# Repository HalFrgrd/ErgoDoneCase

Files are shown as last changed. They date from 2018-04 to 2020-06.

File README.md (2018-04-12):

# ErgoDoneCase
An acrylic case for the ErgoDone PCBs
---
I bought two [ErgoDone PCB's from KBDFans](https://kbdfans.myshopify.com/collections/pcb/products/ergodone-keyboard-pcb-1pcs-free-shipping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) and modified [Litster's ErgoDox acrylic case](https://github.com/bishboria/ErgoDox) to accommodate the changed PCBs. The PCBs are a little different to the standard ErgoDox design:

* Microcontroller is an Arduino Pro Micro instead of Teensy.
* Microcontroller is on left handside instead of right handside.
* IO expander changed from MCP23018 to MCP23017.
* IO expander is now on the right handside.
* Resistors have changed place and orientation.
* LEDs are located on the lefthandside on the top right.

Like Litster's, 3mm acrylic should be used for layers 1 and 5, and 4mm acrylic for the middle layers.
I only had 3mm acrylic so I added nuts between layers 2 and 3 to reaise the PCB. 20mm screws were perfect.

If you want the design without a handrest, replace the bottom half of my designs with the bottom edge of the handrestless designs from Litster. 

See this link about flashing: https://github.com/qmk/qmk_firmware/blob/master/keyboards/ergodox/readme.md

Look at the assembled 2 Layer case album: https://imgur.com/a/fJbaJ

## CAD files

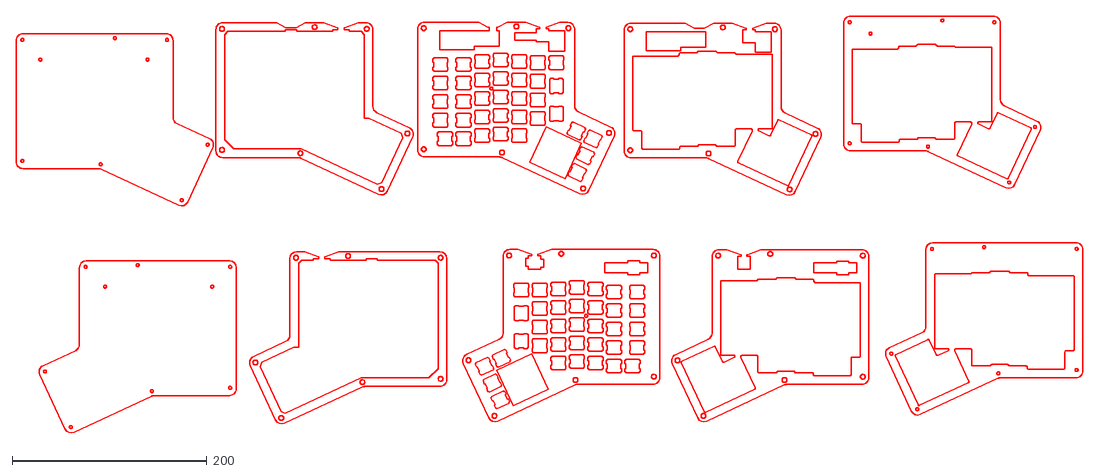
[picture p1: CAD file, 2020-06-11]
ergodonecaseoriginal_standard.dxf
1095.3 x 429.0

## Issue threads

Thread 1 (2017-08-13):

Assembly instructions

harshitgoel96, 2017-08-13:
How to place the pcb inside the case

HalFrgrd, 2017-08-14:
The PCB goes in beneath layer 3. It is held in place by the switches which sit on top of layer 3. Since there is a large number of switches and 2 solder points on each one, the PCB is held in place quite well.

harshitgoel96, 2017-08-15:
Would it be possible for you to make some changes to design to further reduce the design cost? Could you change the  switch plate cutout with Non top removal cutout. And a big rectangle instead of Costar stabilizer. As I want to use Cherry PCB stabilizer

HalFrgrd, 2017-08-16:
What do you mean by non top removal cutout? Do you mean just not having a switch plate?
For the stabilisers, yeah I think I will because with Cherry, they are more popular, and you can mount them into the switch plate from the top, so if you already soldered the switches, you can put in the stabs.

harshitgoel96, 2017-08-16:
The switch plate with perfect square for switches. The one without the space for two clips on both side.

HalFrgrd, 2017-08-16:
Have a look at this website:
http://builder.swillkb.com/
and get the JSON output from this website: http://www.keyboard-layout-editor.com/
Then select square holes and Cherry stabilisers. This will allow you to get the right sizes for the keyholes and the stabiliser holes. It would take a bit of time to modify the switch plate with these new shapes.
Feel free to ask me if you're unsure.

harshitgoel96, 2017-08-16:
i am aware of this. sadly i know nothing about how to modify the file. i lack designing skills

harshitgoel96, 2017-08-19:
hi. i checked the case and plate builder and pulled the ergodox design from kle, but the switch do not align. can you please confirm if they should align or not ?

HalFrgrd, 2017-08-21:
Hi, I have added another design that I think is what you want. The design is different from the one KLE but my design fits the PCB's. KLE might need to update their design as I think it is for an older version of the ErgoDox PCB.

harshitgoel96, 2017-08-21:
aslo are you using the ergodox pcb to match up the cutouts ?

harshitgoel96, 2017-08-21:
also i have opened a pull request to update the cut out. its basically is a big square so that only PCB Mount can be used.

HalFrgrd, 2017-08-23:
I made the case using the acrylic case by Litster.
Thanks for the pull request and I have merged it.

harshitgoel96, 2017-09-05:
I got the 2 layer version made, and its a really nice fit. I share photos once the build is complete

HalFrgrd, 2017-09-05:
That's great! Definitely

harshitgoel96, 2017-09-08:
Hi.
I have assembled the keyboard, it's a perfect fit except a small problem, the cutout for thumb cluster is not big enough, and the  switch do not sit flesh on PCB, they are at an angle due to which the stabs donot fit and the two thumb keys are not sitting quite right.

So I have to fix that. Will update you once I do that.

HalFrgrd, 2017-09-09:
Ah ok. I haven't had much experience with stabs as I forgot to buy them. That would be great ty.

harshitgoel96, 2017-09-10:
link to the album :)
https://imgur.com/a/fJbaJ

Closed 2017-09-10.

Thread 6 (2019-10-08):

Printing instructions

ataquino, 2019-10-08:
Hello.

Are the sizes in millimetres? How should I approach printing these?

Thanks.

HalFrgrd, 2019-10-11:
Hi,

I made these using a laser cutter at a local maker space in Adelaide. Are
you looking to laser cut or 3d print? If you want to laser cut, I don't
really know how to do it myself and I got help at the maker space. I think
it should be straightforward enough if you know someone or have some
instructions on how to use the laser cutter. I think I included how many
layers you need.

Hope this helps,

Feel free to ask any questions, if you're more specific I can probably help
better,

Hal

On Tue, Oct 8, 2019, 9:02 PM Arthur Tavares de Aquino <
notifications@github.com> wrote:

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

ataquino, 2019-10-12:
Yes, I'll laser cut them. But I've decided to try designing my own plates, based off of Ergodox's files.

Thanks :)

Closed 2019-10-12.

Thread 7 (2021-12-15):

printing size when converting to dxf

ongspxm, 2021-12-15:
what should be the scale of the svg file? i have trouble converting it to dxf of the right scale
context: directly converted svg to dxf using https://cloudconvert.com/svg-to-dxf, but seems to be too small

any recommendations on how i should go about doing it instead?

Closed 2025-06-26.

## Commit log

2017-08-20 created two layer design for reduced cost, made larger cutouts to support 1U X 2 keys and 2u PCB Mount stabs
2017-08-21 Added support for square holes
2017-09-10 Added url to Ergodox 2 layer case album
2019-01-02 added placement for tent
    [ergodonecaseoriginal_standard.dxf]
